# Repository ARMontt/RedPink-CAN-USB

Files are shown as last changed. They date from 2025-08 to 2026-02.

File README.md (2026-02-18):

# RedPink-CAN-USB

Mini PCB for STM32C09, useful for general purposes that involves mostly communication through a CANBUS to USB. This board helps to simplify development of industrial devices that requires CANBUS communication. 

## Motivation

Nowadays there are many CAN-USB or CAN-UART devices, that require external coding (usually in C) to test the communication, however, a more user-friendly interface accompanied by a simple CAN-USB device would improve the performance for developing new industrial devices.

## Interactive BOM Viewer

Please feel free to check the Layout and BOM in the following URL: https://armontt.github.io/RedPink-CAN-USB/ibom.html

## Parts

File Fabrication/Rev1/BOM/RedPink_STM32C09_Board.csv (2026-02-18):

Id | Designator | Footprint | Quantity | Designation | Supplier and ref
1 | J4 | PinHeader_1x03_P2.54mm_Vertical | 1 | CANBUS
2 | C6,C5 | C_0603_1608Metric_Pad1.08x0.95mm_HandSolder | 2 | 47pF
3 | C12 | C_0603_1608Metric_Pad1.08x0.95mm_HandSolder | 1 | 4.7uF
4 | R4,R5 | R_0603_1608Metric_Pad0.98x0.95mm_HandSolder | 2 | 60
5 | FL1 | DR221474AE | 1 | DR221-513AE
6 | C3,C2 | C_0603_1608Metric_Pad1.08x0.95mm_HandSolder | 2 | 1uF
7 | C14 | C_0603_1608Metric_Pad1.08x0.95mm_HandSolder | 1 | 10nF
8 | IC1 | QFP50P900X900X160-48N | 1 | STM32C092CBT6
9 | C10,C11 | C_0603_1608Metric_Pad1.08x0.95mm_HandSolder | 2 | 6pF
10 | C15,C7,C13 | C_0603_1608Metric_Pad1.08x0.95mm_HandSolder | 3 | 100nF
11 | C8 | C_0603_1608Metric_Pad1.08x0.95mm_HandSolder | 1 | 100n
12 | JP1 | SolderJumper-2_P1.3mm_Open_RoundedPad1.0x1.5mm | 1 | Jumper_2_Open
13 | J2 | PinHeader_1x04_P2.54mm_Vertical | 1 | SWD DEBUG
14 | R2,R1 | R_0603_1608Metric_Pad0.98x0.95mm_HandSolder | 2 | 27
15 | R3 | R_0603_1608Metric_Pad0.98x0.95mm_HandSolder | 1 | 5.1k
16 | C4 | C_0603_1608Metric_Pad1.08x0.95mm_HandSolder | 1 | 0.1uF
17 | R6,R7 | R_0603_1608Metric_Pad0.98x0.95mm_HandSolder | 2 | 10k
18 | IC4 | LDO SOT95P280X145-5N | 1 | LDLN025M18R
19 | C9 | C_0603_1608Metric_Pad1.08x0.95mm_HandSolder | 1 | 4700pF
20 | IC5 | FTDI SOP64P599X175-20N | 1 | FT231XS-U
21 | Y1 | NX3225GD8MHZSTDCRA3 | 1 | NX3225GD-8MHZ-STD-CRA-3
22 | FB1 | BLM18SP221SN1B | 1 | 600R 0.85A
23 | D1 | SOT-23 | 1 | NUP2105L
24 | J1 | USB421603A | 1 | USB4216-03-A
25 | C1 | C_0603_1608Metric_Pad1.08x0.95mm_HandSolder | 1 | 22u
26 | IC3 | CANBUS SOIC127P600X175-8N | 1 | ATA6561-GAQW-N

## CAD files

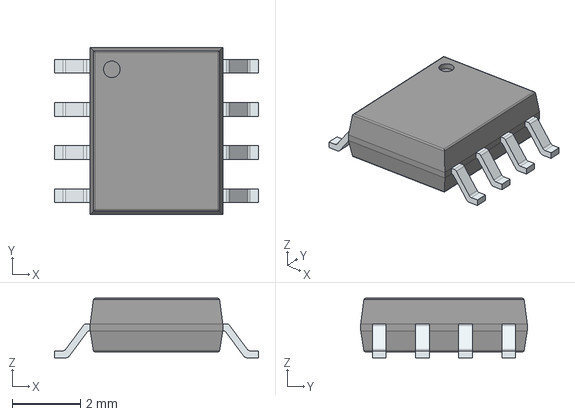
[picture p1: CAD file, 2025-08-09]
Components/ATA6561-GAQW-N CAN TRANSCEIVER/3D/ATA6561-GAQW-N.stp
6.00 x 4.90 x 1.75 mm
PinsArrayLR

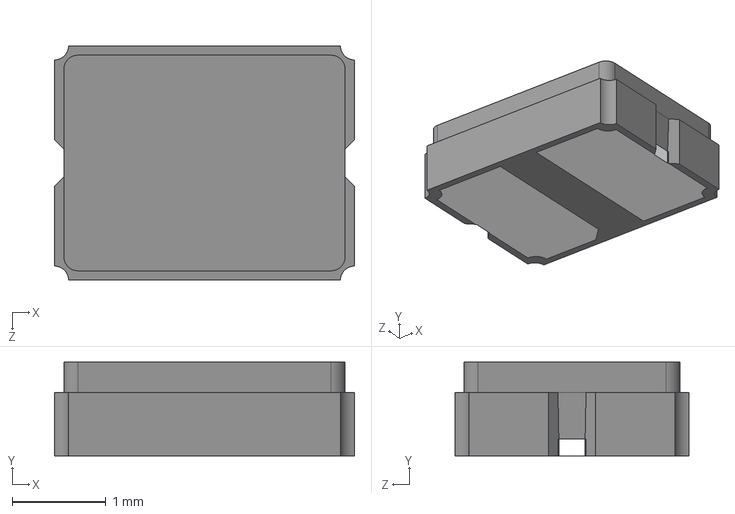
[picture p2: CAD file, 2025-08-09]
Components/CRYSTAL8MHz/3D/NX3225GD-8MHZ-STD-CRA-3.stp
3.20 x 1.00 x 2.50 mm

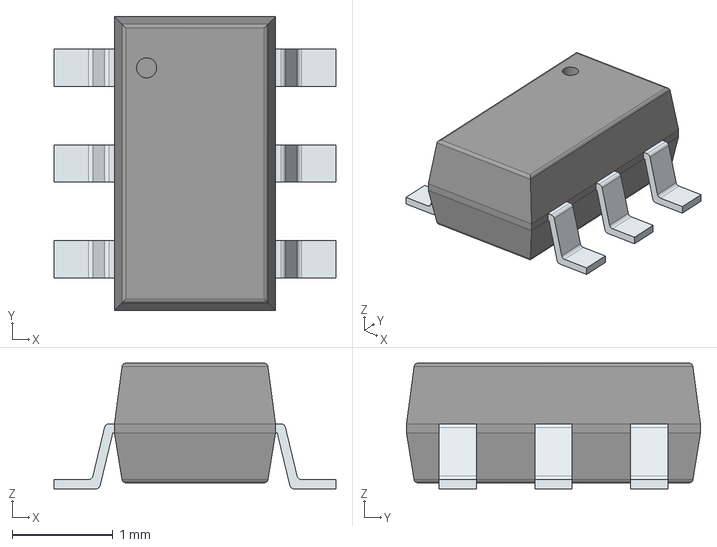
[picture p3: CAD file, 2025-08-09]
Components/DCP3601NMR/3D/DCP3601NMR.stp
2.80 x 2.92 x 1.25 mm
PinsArrayLR

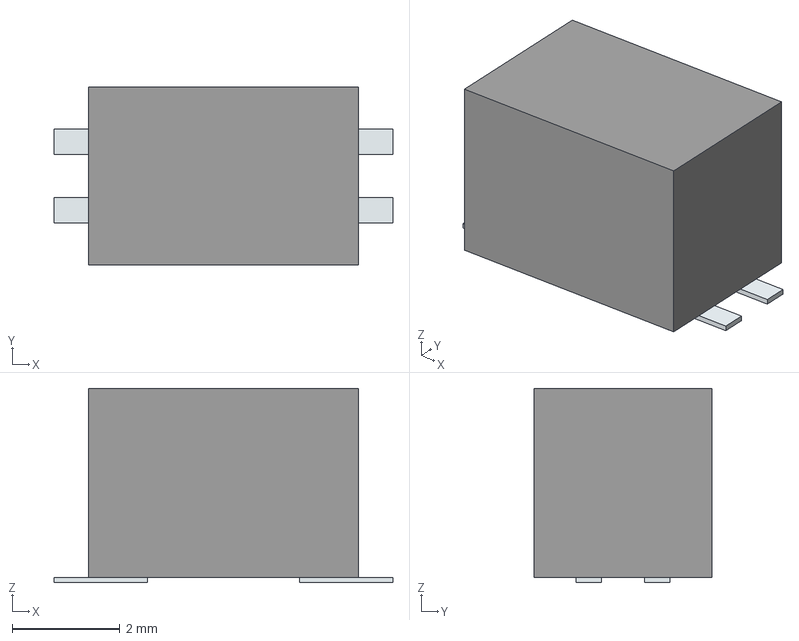
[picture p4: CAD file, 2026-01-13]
Components/DR221-513AE/3D/DR221-513AE.stp
6.28 x 3.30 x 3.60 mm
Pins

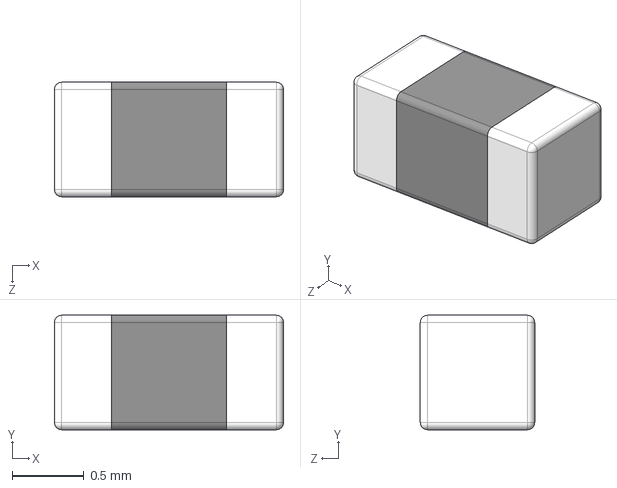
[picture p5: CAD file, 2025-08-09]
Components/FERRITE BREAD/3D/BLM18HE601SN1D.stp
1.60 x 0.8 x 0.8 mm

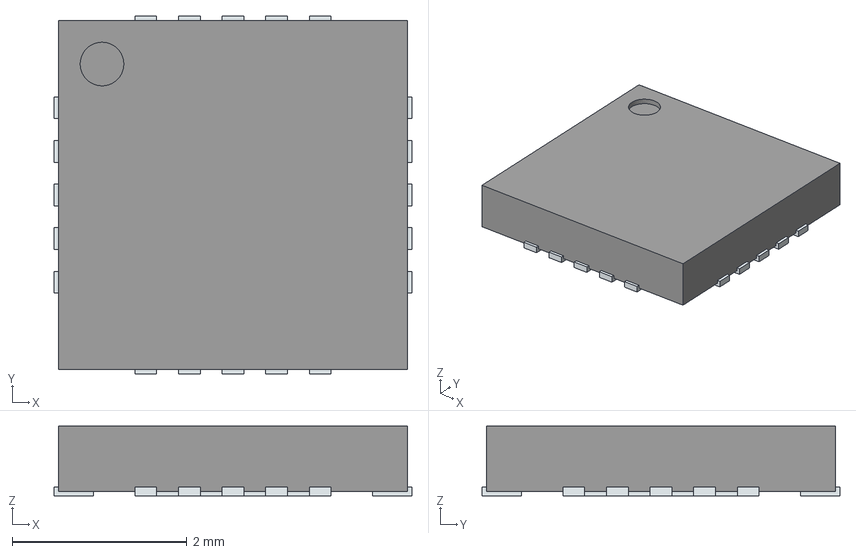
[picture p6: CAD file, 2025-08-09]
Components/FT231XQ-R/3D/FT231XQ-R.stp
4.10 x 4.10 x 0.8 mm
ThermalPin
PinsArrayLR
PinsArrayTB

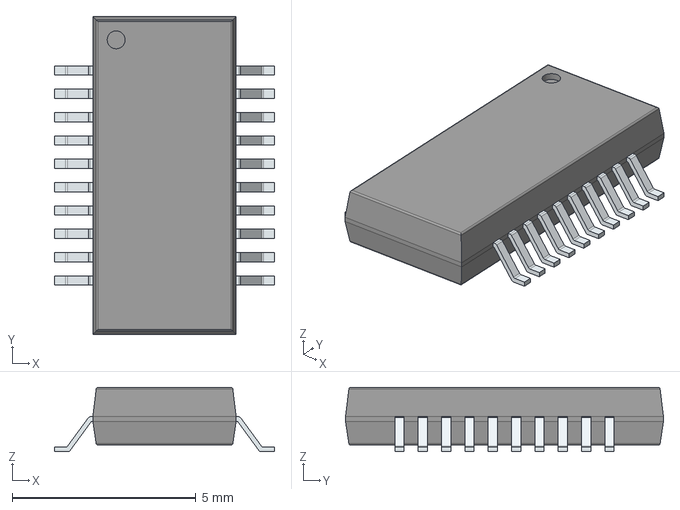
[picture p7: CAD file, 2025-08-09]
Components/FT231XS-U/3D/FT231XS-U.stp
5.99 x 8.65 x 1.75 mm
PinsArrayLR

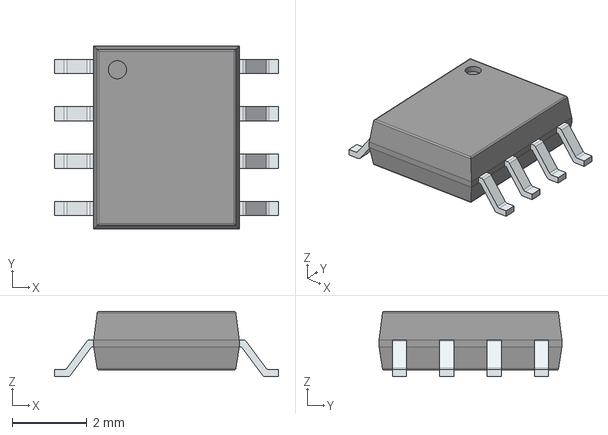
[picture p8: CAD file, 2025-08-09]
Components/L9616-TR/3D/L9616-TR.stp
6.00 x 4.90 x 1.75 mm
PinsArrayLR

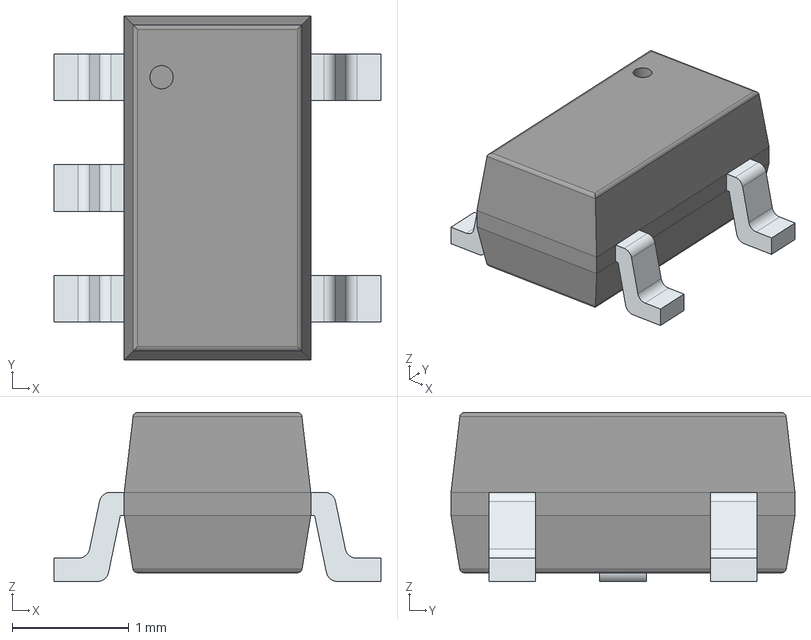
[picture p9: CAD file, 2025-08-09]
Components/LDLN025M18R/3D/LDLN025M18R.stp
2.80 x 2.95 x 1.45 mm
PinsArrayL
PinsArrayR

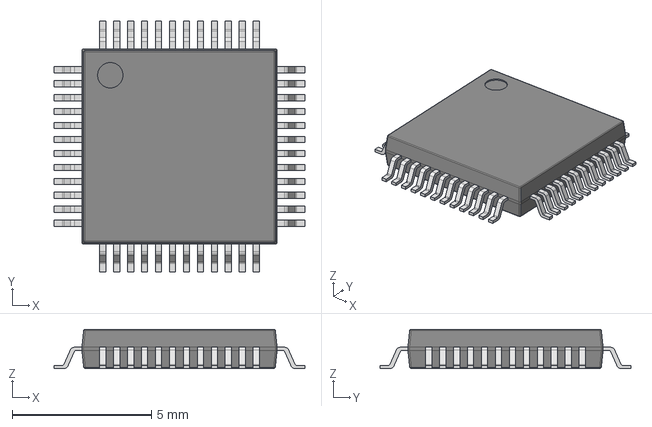
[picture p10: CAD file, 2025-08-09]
Components/STM32C092CBT6/3D/STM32C092CBT6.stp
9.00 x 9.00 x 1.41 mm

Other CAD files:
Components/ST4E1240DT/3D/ST4E1240DT.stp

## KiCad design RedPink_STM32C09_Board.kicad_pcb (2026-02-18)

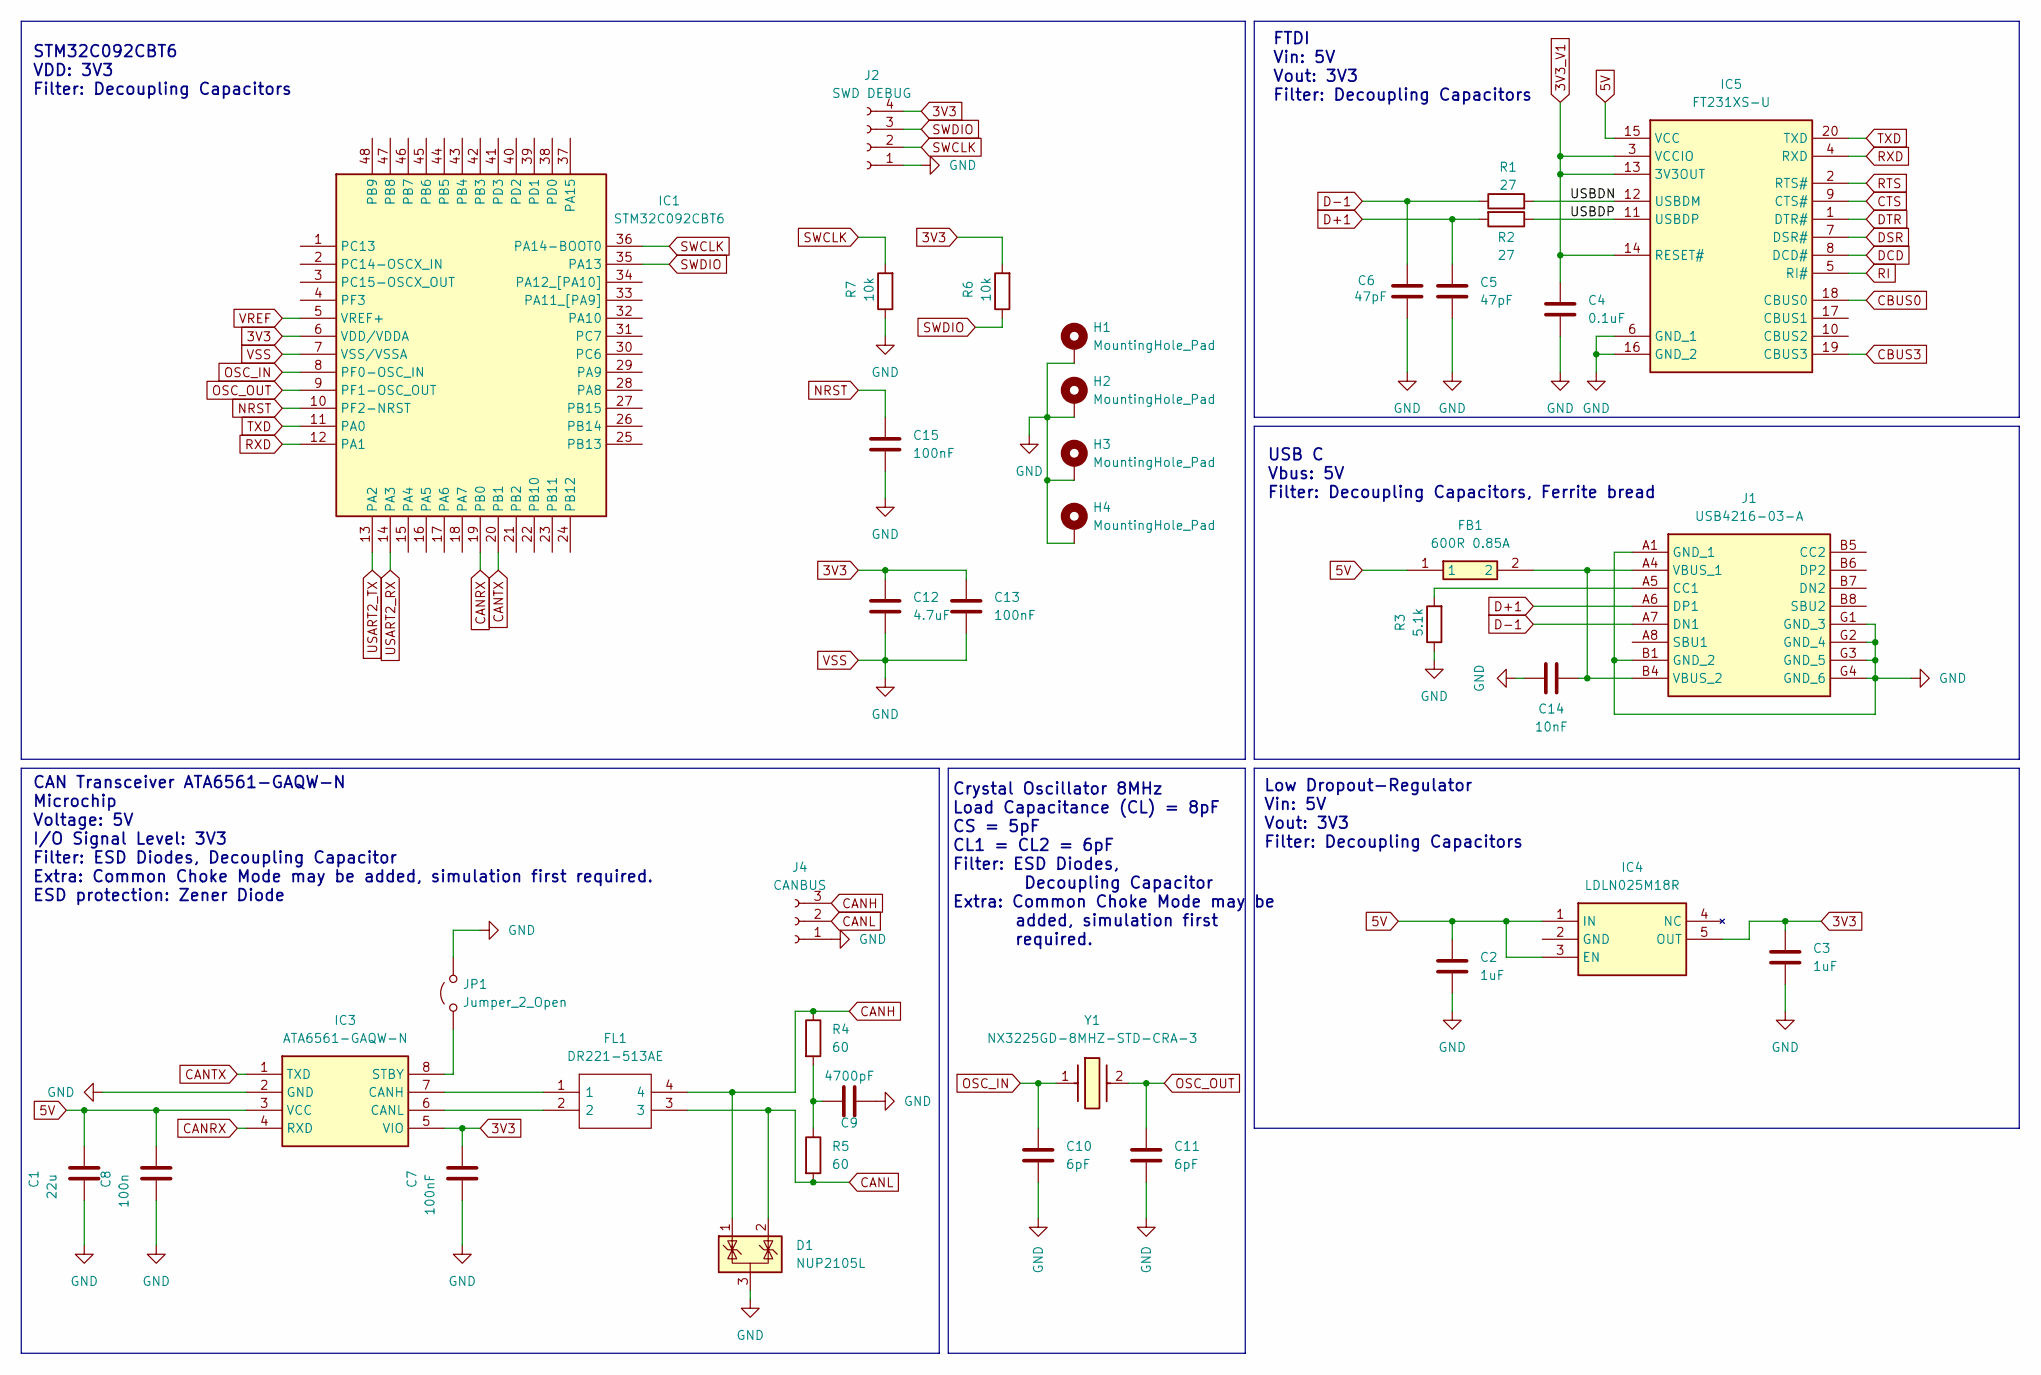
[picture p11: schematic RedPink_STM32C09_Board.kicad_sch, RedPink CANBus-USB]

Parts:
C1: 22u; C_0603_1608Metric_Pad1.08x0.95mm_HandSolder
C2, C3: 1uF; C_0603_1608Metric_Pad1.08x0.95mm_HandSolder
C4: 0.1uF; C_0603_1608Metric_Pad1.08x0.95mm_HandSolder
C5, C6: 47pF; C_0603_1608Metric_Pad1.08x0.95mm_HandSolder
C7, C13, C15: 100nF; C_0603_1608Metric_Pad1.08x0.95mm_HandSolder
C8: 100n; C_0603_1608Metric_Pad1.08x0.95mm_HandSolder
C9: 4700pF; C_0603_1608Metric_Pad1.08x0.95mm_HandSolder
C10, C11: 6pF; C_0603_1608Metric_Pad1.08x0.95mm_HandSolder
C12: 4.7uF; C_0603_1608Metric_Pad1.08x0.95mm_HandSolder
C14: 10nF; C_0603_1608Metric_Pad1.08x0.95mm_HandSolder
D1: NUP2105L; SOT-23
FB1: 600R 0.85A; BLM18SP221SN1B; Mouser Part Number 81-BLM18HE601SN1D
FL1: DR221-513AE; DR221474AE; Mouser Part Number 652-DR221-513AE
H1, H2, H3, H4: MountingHole_Pad; MountingHole_2.5mm_Pad
IC1: STM32C092CBT6; QFP50P900X900X160-48N; Manufacturer_Part_Number STM32C092CBT6
IC3: ATA6561-GAQW-N; CANBUS SOIC127P600X175-8N; Mouser Part Number 579-ATA6561-GAQW-N
IC4: LDLN025M18R; LDO SOT95P280X145-5N; Mouser Part Number 511-LDLN025M18R
IC5: FT231XS-U; FTDI SOP64P599X175-20N; Mouser Part Number 895-FT231XS-U
J1: USB4216-03-A; USB421603A; Mouser Part Number 640-USB4216-03-A
J2: SWD DEBUG; PinHeader_1x04_P2.54mm_Vertical
J4: CANBUS; PinHeader_1x03_P2.54mm_Vertical
JP1: Jumper_2_Open; SolderJumper-2_P1.3mm_Open_RoundedPad1.0x1.5mm
R1, R2: 27; R_0603_1608Metric_Pad0.98x0.95mm_HandSolder
R3: 5.1k; R_0603_1608Metric_Pad0.98x0.95mm_HandSolder
R4, R5: 60; R_0603_1608Metric_Pad0.98x0.95mm_HandSolder
R6, R7: 10k; R_0603_1608Metric_Pad0.98x0.95mm_HandSolder
Y1: NX3225GD-8MHZ-STD-CRA-3; NX3225GD8MHZSTDCRA3; Mouser Part Number 344-NX3225GD8MCRA3

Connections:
3V3: C3.1, C7.2, C12.1, C13.1, IC1.6 (VDD/VDDA), IC3.5 (VIO), IC4.5 (OUT), J2.4, R6.2
3V3_V1: C4.1, IC5.3 (VCCIO), IC5.13 (3V3OUT), IC5.14 (RESET#)
5V: C1.2, C2.1, C8.2, FB1.1, IC3.3 (VCC), IC4.1 (IN), IC4.3 (EN), IC5.15 (VCC)
/USBDN: IC5.12 (USBDM), R1.2
/USBDP: IC5.11 (USBDP), R2.1
CANH: D1.1 (K), FL1.4, J4.3, R4.1
CANL: D1.2 (K), FL1.3, J4.2, R5.2
CANRX: IC1.19 (PB0), IC3.4 (RXD)
CANTX: IC1.20 (PB1), IC3.1 (TXD)
CBUS0: IC5.18 (CBUS0)
CBUS3: IC5.19 (CBUS3)
CTS: IC5.9 (CTS#)
D+1: C5.1, J1.A6 (DP1), R2.2
D-1: C6.1, J1.A7 (DN1), R1.1
DCD: IC5.8 (DCD#)
DSR: IC5.7 (DSR#)
DTR: IC5.1 (DTR#)
NRST: C15.1, IC1.10 (PF2-NRST)
unnamed: C9.1, R4.2, R5.1
unnamed: FL1.1, IC3.7 (CANH)
unnamed: FL1.2, IC3.6 (CANL)
unnamed: IC3.8 (STBY), JP1.1 (A)
unnamed: J1.A5 (CC1), R3.2
unnamed: C14.2, FB1.2, J1.A4 (VBUS_1), J1.B4 (VBUS_2)
OSC_IN: C10.1, IC1.8 (PF0-OSC_IN), Y1.1
OSC_OUT: C11.1, IC1.9 (PF1-OSC_OUT), Y1.2
RI: IC5.5 (RI#)
RTS: IC5.2 (RTS#)
RXD: IC1.12 (PA1), IC5.4 (RXD)
SWCLK: IC1.36 (PA14-BOOT0), J2.2, R7.2
SWDIO: IC1.35 (PA13), J2.3, R6.1
TXD: IC1.11 (PA0), IC5.20 (TXD)
USART2_RX: IC1.14 (PA3)
USART2_TX: IC1.13 (PA2)
VREF: IC1.5 (VREF+)
VSS: C1.1, C2.2, C3.2, C4.2, C5.2, C6.2, C7.1, C8.1, C9.2, C10.2, C11.2, C12.2, C13.2, C14.1, C15.2, D1.3 (A), H1.1, H2.1, H3.1, H4.1, IC1.7 (VSS/VSSA), IC3.2 (GND), IC5.6 (GND_1), IC5.16 (GND_2), J1.A1 (GND_1), J1.B1 (GND_2), J1.G1 (GND_3), J1.G2 (GND_4), J1.G3 (GND_5), J1.G4 (GND_6), J2.1, J4.1, JP1.2 (B), R3.1, R7.1

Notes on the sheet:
STM32C092CBT6 VDD: 3V3 Filter: Decoupling Capacitors
Crystal Oscillator 8MHz Load Capacitance (CL) = 8pF CS = 5pF CL1 = CL2 = 6pF Filter: ESD Diodes, Decoupling Capacitor Extra: Common Choke Mode may be added, simulation first required.
CAN Transceiver ATA6561-GAQW-N Microchip Voltage: 5V I/O Signal Level: 3V3 Filter: ESD Diodes, Decoupling Capacitor Extra: Common Choke Mode may be added, simulation first required. ESD protection: Zener Diode
Low Dropout-Regulator Vin: 5V Vout: 3V3 Filter: Decoupling Capacitors
FTDI Vin: 5V Vout: 3V3 Filter: Decoupling Capacitors
USB C Vbus: 5V Filter: Decoupling Capacitors, Ferrite bread

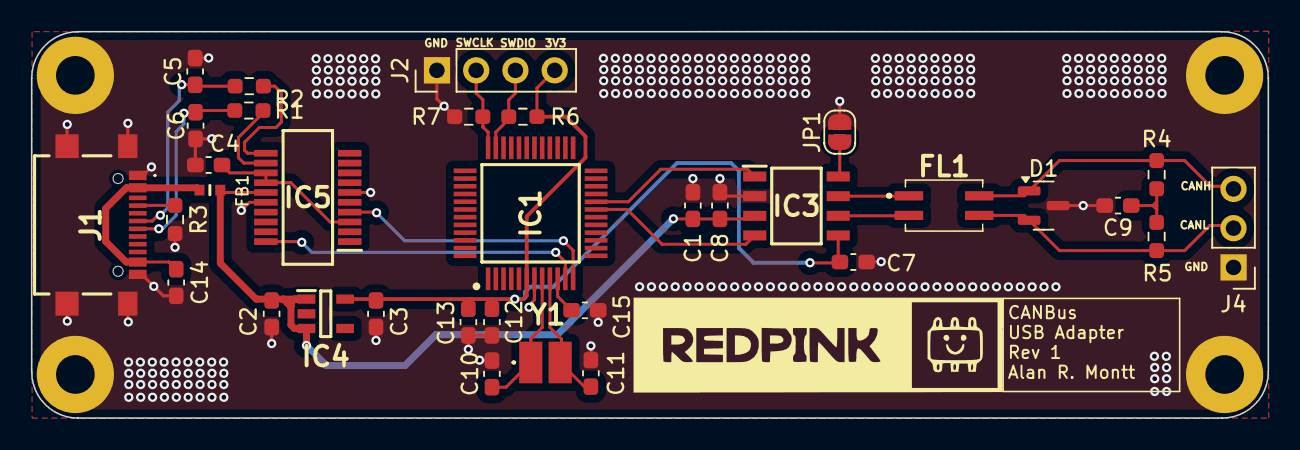
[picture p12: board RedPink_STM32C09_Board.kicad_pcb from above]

Board: 2 copper layers, 80.0 x 25.0 mm, 38 parts (0 on the bottom side), 25 nets.

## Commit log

2025-03-06 Files created
    [BBNQ00160808601Y00.stp, CommunicationRS485_CAN.kicad_sch, NX3225GD-8MHZ-STD-CRA-3.stp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]
2025-08-09 New version of RedPink Board
    Replaced STM32L4 design, changed to STM32C09
    [ATA6561-GAQW-N.stp, BLM18HE601SN1D.stp, DCP3601NMR.stp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]
2026-01-13 Updated design - focus on CAN-USB Application
    [DR221-513AE.stp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]
2026-02-18 Updated PCB layout, output connector replaced
    1) Removed 5V pin from output pin header
    2) Added round corners
    3) Replace pin header output
    [RedPink_STM32C09_Board-B_Cu.gbr, RedPink_STM32C09_Board-B_Mask.gbr, RedPink_STM32C09_Board-B_Paste.gbr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]
2026-02-18 Interactive BOM Added
2026-02-18 Add Interactive BOM Viewer section to README
    Added section for Interactive BOM Viewer with URL.
